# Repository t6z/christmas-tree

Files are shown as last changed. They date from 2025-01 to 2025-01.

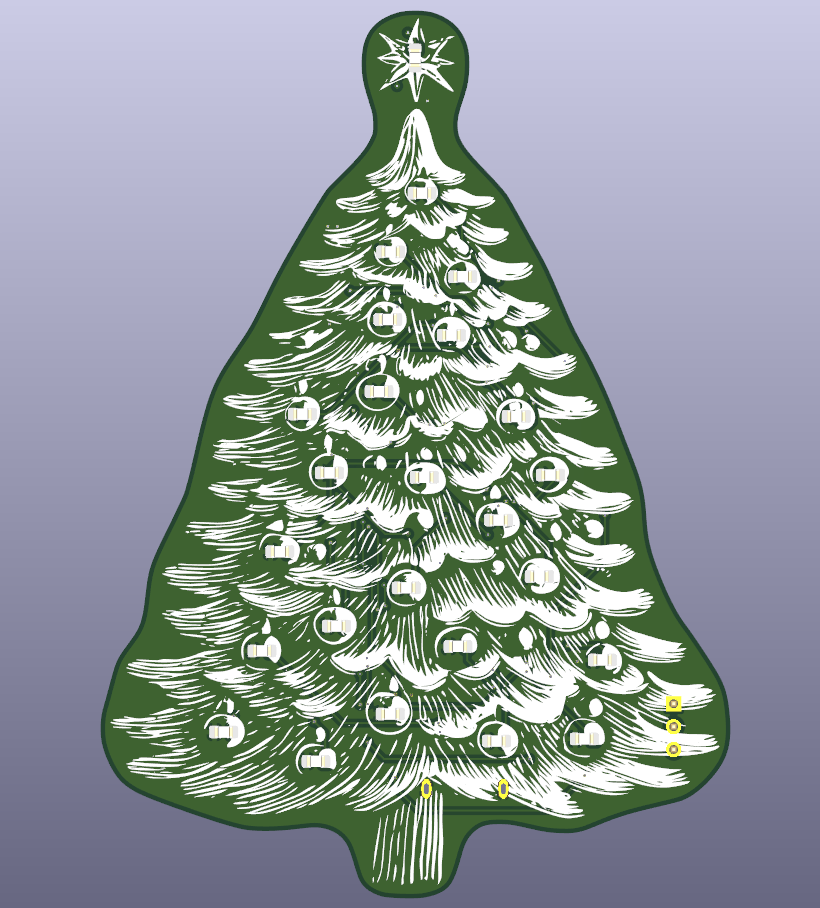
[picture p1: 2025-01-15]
images/xmas-tree-v2.png

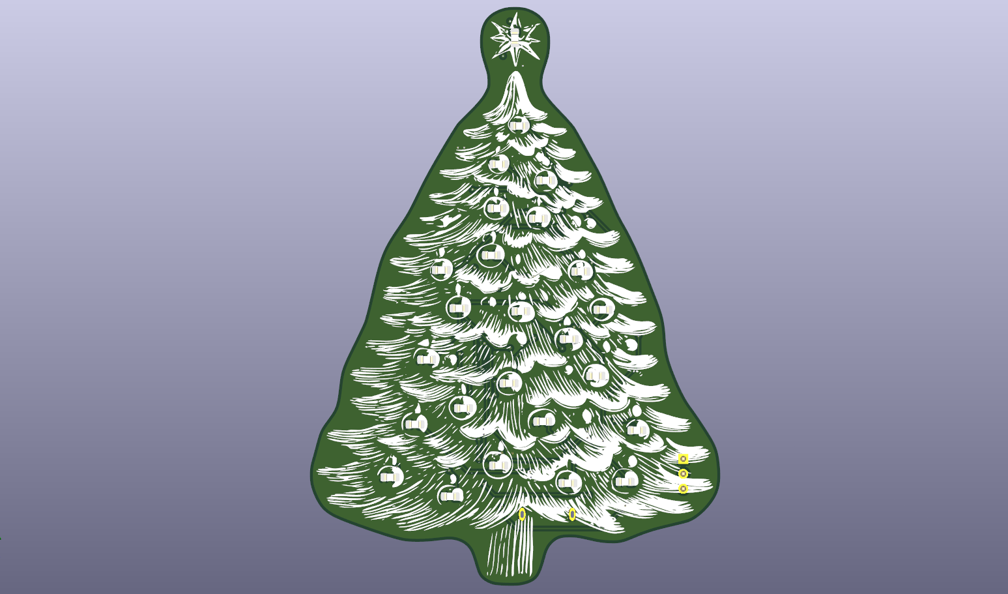
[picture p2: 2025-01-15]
images/xmas-tree.png

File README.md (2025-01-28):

# Christmas Tree

I made a little Christmas tree that lights up and plays a song through a buzzer. I wanted a simple project to expand my skills with schematic capture and PCB layout, and to see how accurate the quick turnaround prototype shops (PCBWAY) do. This project uses an ATTiny402, 3 shift registers to control the LED's, and a simple circuit to try a piezo buzzer. I used Kicad as my EDA tool. It was fun using AI + InkScape to generate different graphics for the tree and import them for the edge cut and silkscreen layers.

christmas-tree-leds

## Building Code

### Prereqs

__AVR GNU Toolchain__:

I use the AVR GNU Toolchain (GNU Binutils, GCC, AVR-LibC) to build my code. The attiny402 is supported in the AVR-LibC 2.2.0 release, but ubuntu 24.04 LTS repository only has v2.0.0 (as of December 2024). You could build GNU Binutils, GCC, and AVR-LibC from scratch, but luckily this nice guy already has: [avr-gcc-build](https://github.com/ZakKemble/avr-gcc-build)

I'm using the 14.1.0 (2024-06-14) Release. I downloaded it and extracted it into `~/avr`.

__AVR Dude__:

I downloaded the v8.0 Release of AVR Dude from the [official GitHub repository](https://github.com/avrdudes/avrdude) and extracted it into `~/avr`.

### Building

Run `make`

```bash
$ make
mkdir -p build/src
~/avr/avr-gcc-14.1.0-x64-linux/bin/avr-gcc -c -o build/src/main.o  -std=c11 -Wall -Wextra -Werror -mmcu=attiny402 -DF_CPU=3333333UL -O1 -g -gdwarf-2 -Wl,-Map,build/christmas-tree.map -DDEBUG  src/main.c
mkdir -p build/src
~/avr/avr-gcc-14.1.0-x64-linux/bin/avr-gcc -c -o build/src/notes.o  -std=c11 -Wall -Wextra -Werror -mmcu=attiny402 -DF_CPU=3333333UL -O1 -g -gdwarf-2 -Wl,-Map,build/christmas-tree.map -DDEBUG  src/notes.c
mkdir -p build/src
~/avr/avr-gcc-14.1.0-x64-linux/bin/avr-gcc -c -o build/src/rtttl.o  -std=c11 -Wall -Wextra -Werror -mmcu=attiny402 -DF_CPU=3333333UL -O1 -g -gdwarf-2 -Wl,-Map,build/christmas-tree.map -DDEBUG  src/rtttl.c
mkdir -p build/src
~/avr/avr-gcc-14.1.0-x64-linux/bin/avr-gcc -c -o build/src/tunes.o  -std=c11 -Wall -Wextra -Werror -mmcu=attiny402 -DF_CPU=3333333UL -O1 -g -gdwarf-2 -Wl,-Map,build/christmas-tree.map -DDEBUG  src/tunes.c
~/avr/avr-gcc-14.1.0-x64-linux/bin/avr-gcc -o build/christmas-tree.elf build/src/main.o build/src/notes.o build/src/rtttl.o build/src/tunes.o  -std=c11 -Wall -Wextra -Werror -mmcu=attiny402 -DF_CPU=3333333UL -O1 -g -gdwarf-2 -Wl,-Map,build/christmas-tree.map -DDEBUG 
~/avr/avr-gcc-14.1.0-x64-linux/bin/avr-objdump -h -S build/christmas-tree.elf > build/christmas-tree.lst
~/avr/avr-gcc-14.1.0-x64-linux/bin/avr-size build/christmas-tree.elf
   text	  data	   bss	   dec	   hex	filename
   3586	   156	    44	  3786	   eca	build/christmas-tree.elf
~/avr/avr-gcc-14.1.0-x64-linux/bin/avr-objcopy -j .text -j .data -O ihex build/christmas-tree.elf build/christmas-tree.hex
~/avr/avr-gcc-14.1.0-x64-linux/bin/avr-objcopy -j .text -j .data -O binary build/christmas-tree.elf build/christmas-tree.bin
```

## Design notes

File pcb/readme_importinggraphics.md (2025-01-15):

When importing the SVG's to Kicad via the File > Import > Graphics utility, I used a 0.375000 scale

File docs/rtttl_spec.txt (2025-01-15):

RTTTL Format Specifications

RTTTL (RingTone Text Transfer Language) is the primary format used to distribute 
ringtones for Nokia phones. An RTTTL file is a text file, containing the 
ringtone name, a control section and a section containing a comma separated 
sequence of ring tone commands. White space must be ignored by any reader 
application. 

Example: 
Simpsons:d=4,o=5,b=160:32p,c.6,e6,f#6,8a6,g.6,e6,c6,8a,8f#,8f#,8f#,2g

This file describes a ringtone whose name is 'Simpsons'. The control section 
sets the beats per minute at 160, the default note length as 4, and the default 
scale as Octave 5. 
<RTX file> := <name> ":" [<control section>] ":" <tone-commands>

	<name> := <char> ; maximum name length 10 characters

	<control-section> := <control-pair> ["," <control-section>]

		<control-pair> := <control-name> ["="] <control-value>

		<control-name> := "o" | "d" | "b"
		; Valid in control section: o=default scale, d=default duration, b=default beats per minute. 
		; if not specified, defaults are 4=duration, 6=scale, 63=beats-per-minute
		; any unknown control-names must be ignored

		<tone-commands> := <tone-command> ["," <tone-commands>]

		<tone-command> :=<note> | <control-pair>

		<note> := [<duration>] <note> [<scale>] [<special-duration>] <delimiter>

			<duration> := "1" | "2" | "4" | "8" | "16" | "32" 
			; duration is divider of full note duration, eg. 4 represents a quarter note

			<note> := "P" | "C" | "C#" | "D" | "D#" | "E" | "F" | "F#" | "G" | "G#" | "A" | "A#" | "B" 

			<scale> :="4" | "5" | "6" | "7"
			; Note that octave 4: A=440Hz, 5: A=880Hz, 6: A=1.76 kHz, 7: A=3.52 kHz
			; The lowest note on the Nokia 61xx is A4, the highest is B7

			<special-duration> := "." ; Dotted note

; End of specification

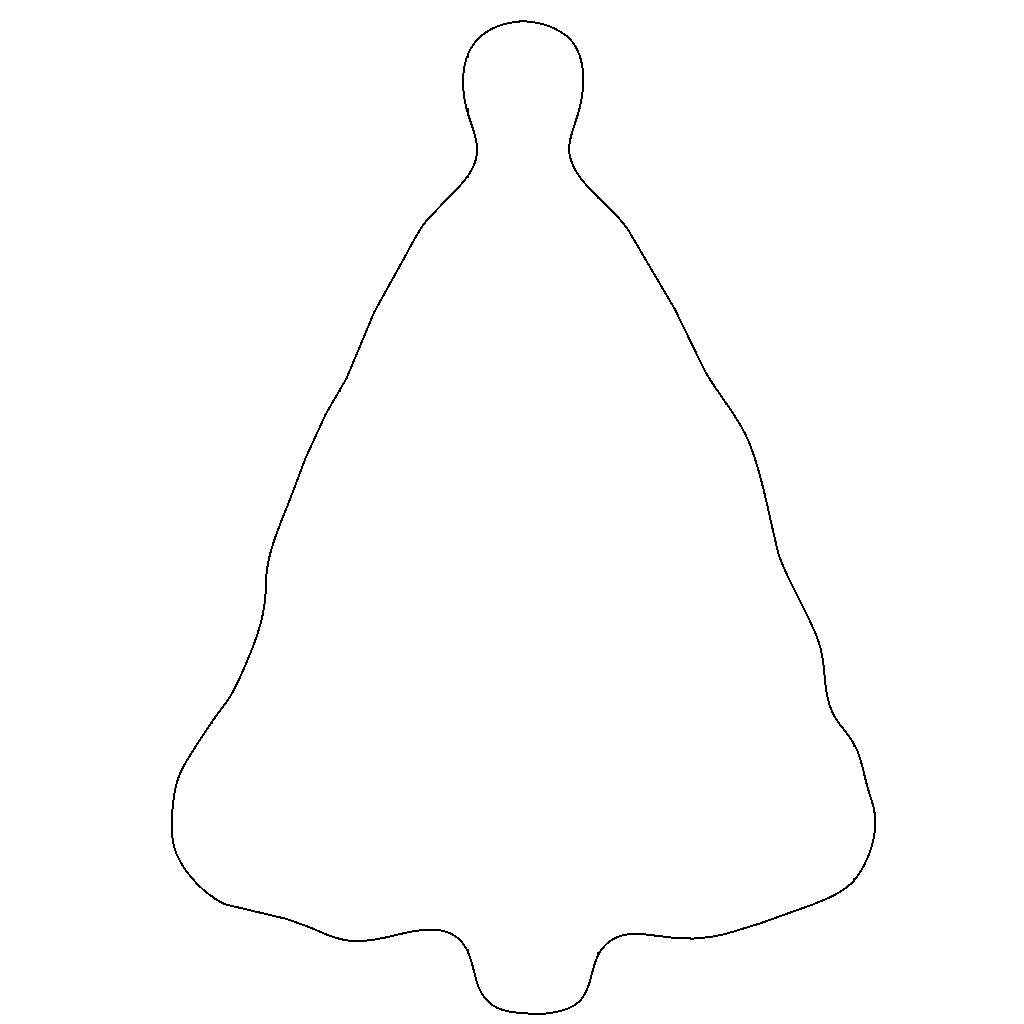
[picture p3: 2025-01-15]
images/tree-outline.png

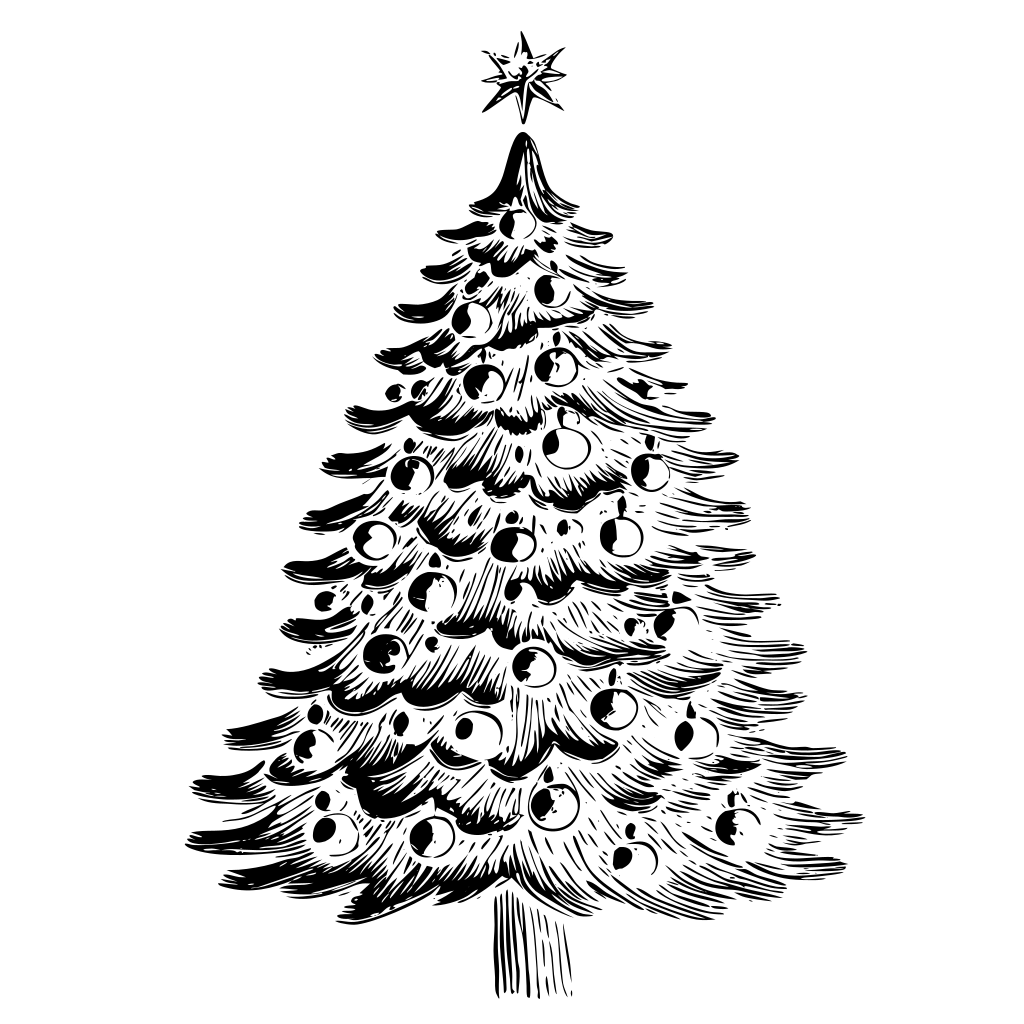
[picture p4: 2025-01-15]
images/tree.png

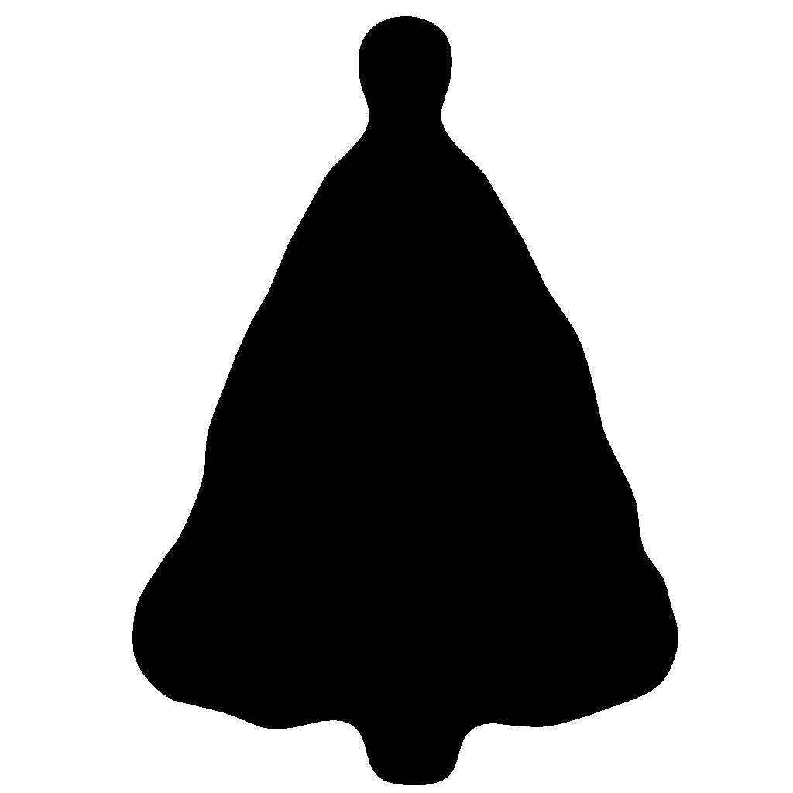
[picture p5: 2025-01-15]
images/tree-filled.png

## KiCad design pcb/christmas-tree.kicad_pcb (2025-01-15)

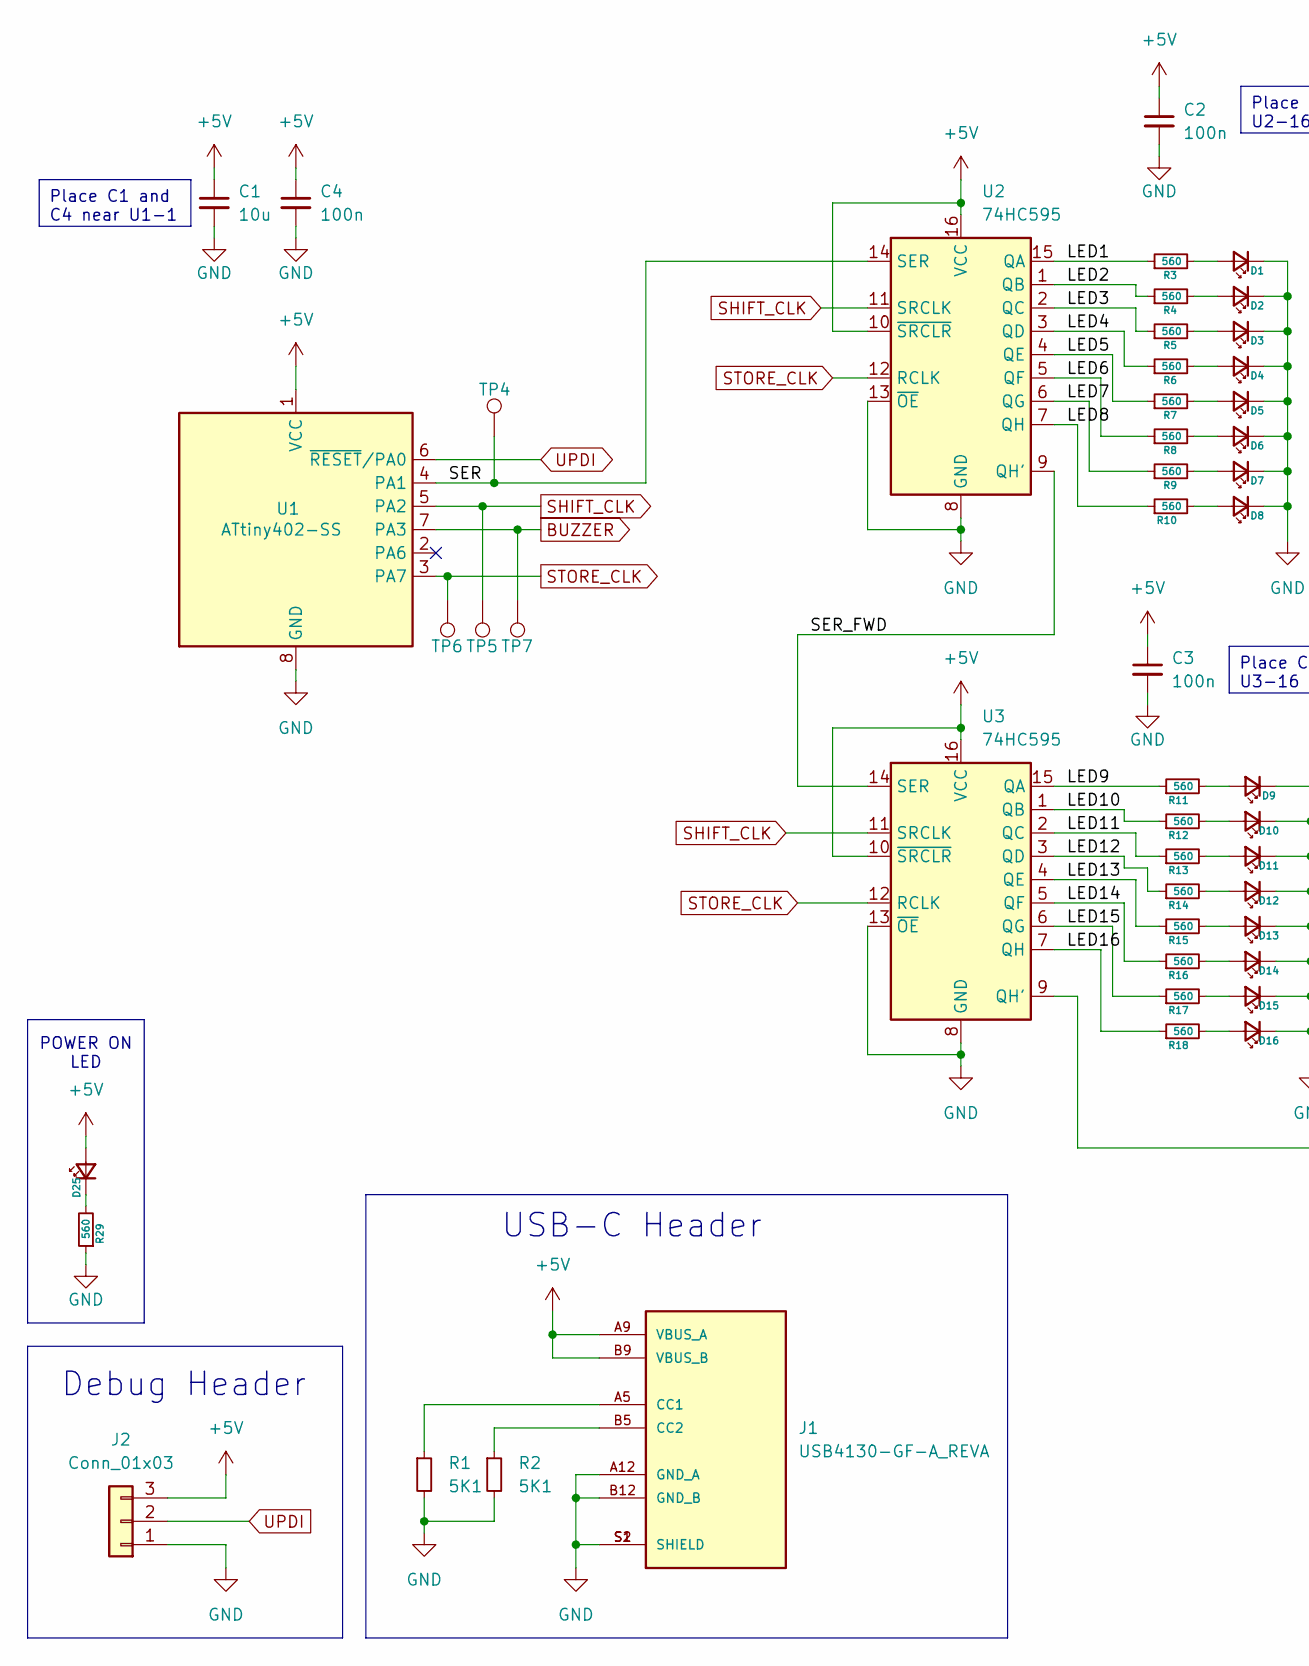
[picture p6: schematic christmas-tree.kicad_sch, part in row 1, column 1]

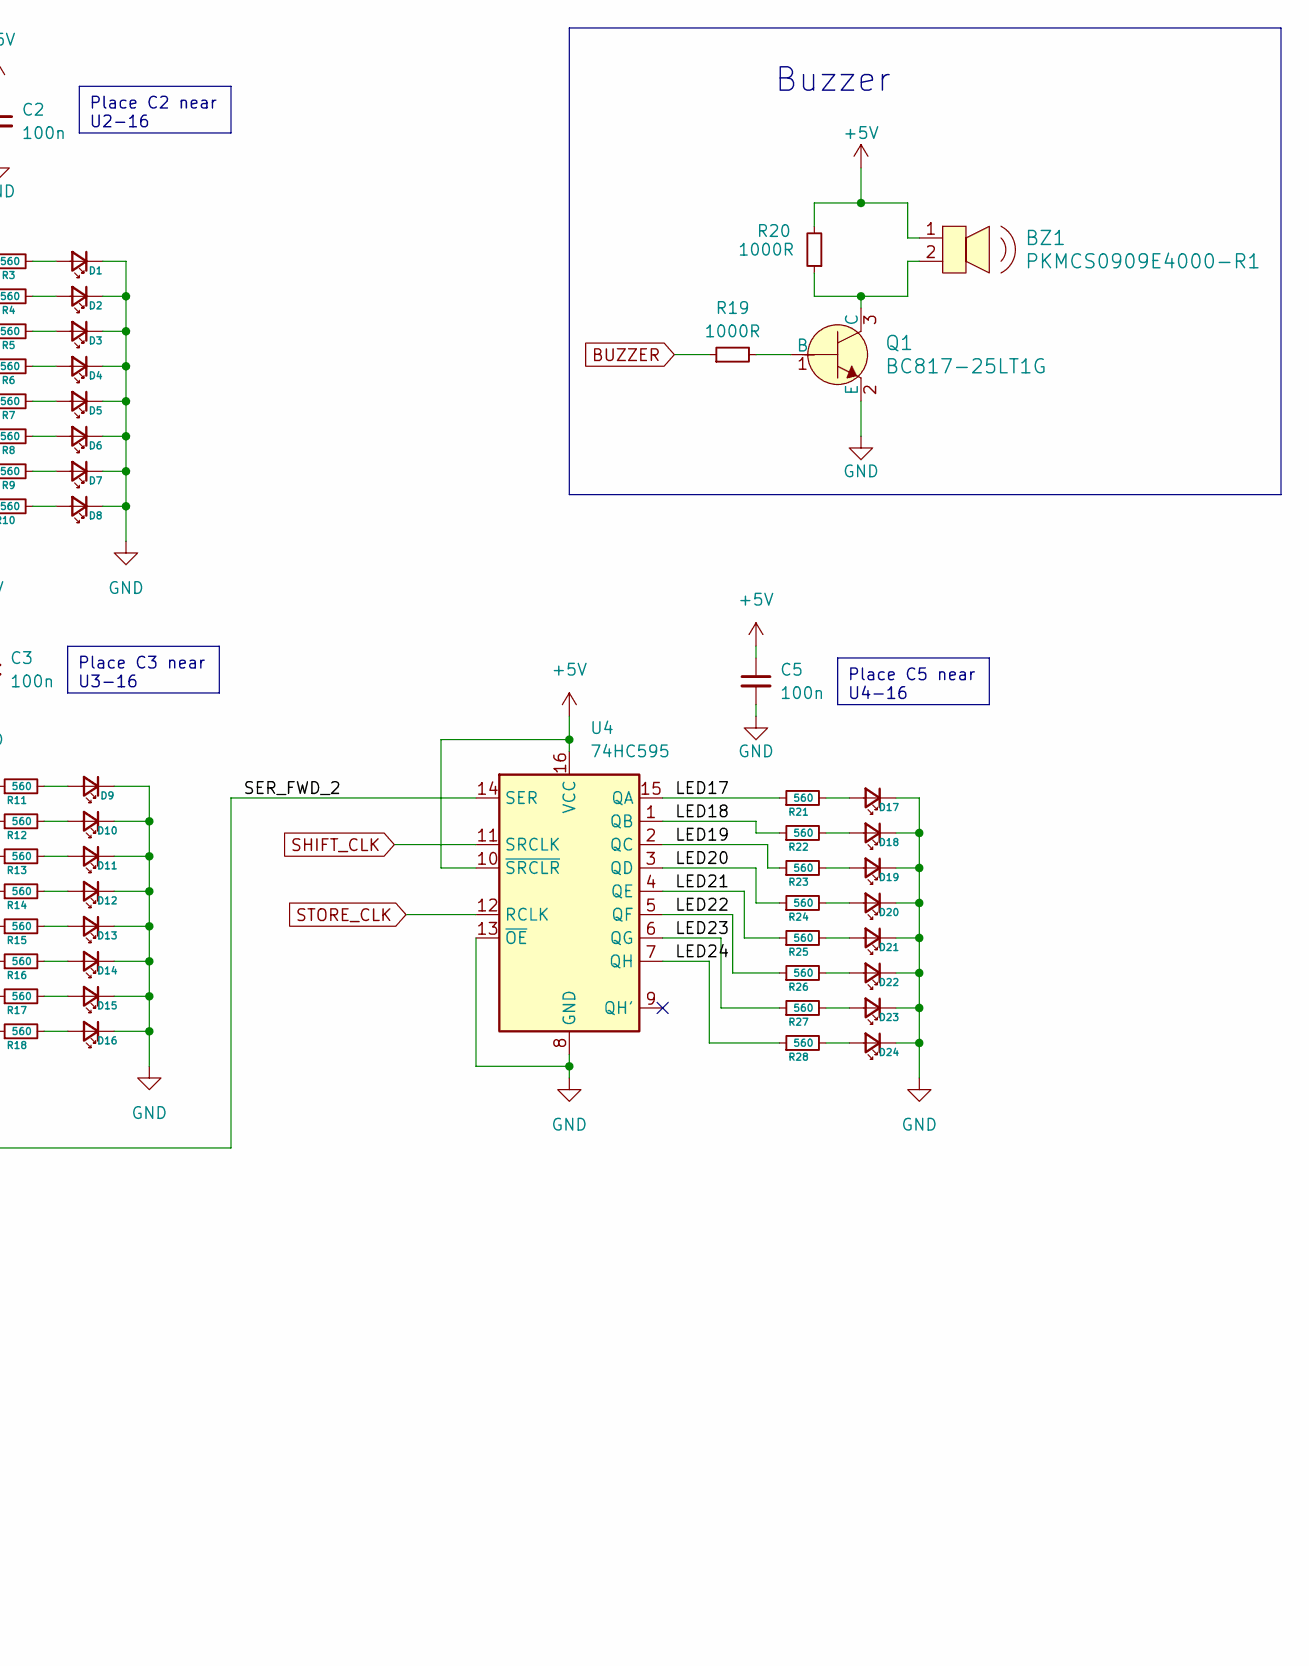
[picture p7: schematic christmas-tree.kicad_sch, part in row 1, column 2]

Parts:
BZ1: PKMCS0909E4000-R1; Piezo_9x9mm_PKMCS0909E4000-R1; MPN PKMCS0909E4000-R1; Digi-Key_PN 490-9647-1-ND
C1: 10u; C_0805_2012Metric_Pad1.18x1.45mm_HandSolder
C2, C3, C4, C5: 100n; C_0805_2012Metric_Pad1.18x1.45mm_HandSolder
D1, D2, D3, D4, D5, D6, D7, D8, D9, D10, D11, D12, D13, D14, D15, D16, D17, D18, D19, D20, D21, D22, D23, D24, D25: LED_Small; LED_0805_2012Metric_Pad1.15x1.40mm_HandSolder
J1: USB4130-GF-A_REVA; GCT_USB4130-GF-A_REVA; PARTREV A
J2: Conn_01x03; PinHeader_1x03_P2.54mm_Vertical
Q1: BC817-25LT1G; SOT-23-3; MPN BC817-25LT1G; Digi-Key_PN BC817-25LT1GOSCT-ND
R1, R2: 5K1; R_0805_2012Metric_Pad1.20x1.40mm_HandSolder
R3, R4, R5, R6, R7, R8, R9, R10, R11, R12, R13, R14, R15, R16, R17, R18, R21, R22, R23, R24, R25, R26, R27, R28, R29: 560; R_0805_2012Metric_Pad1.20x1.40mm_HandSolder
R19, R20: 1000R; R_0805_2012Metric_Pad1.20x1.40mm_HandSolder
TP4: SER; TestPoint_Pad_D1.0mm
TP5: SHIFT_CLK; TestPoint_Pad_D1.0mm
TP6: STORE_CLK; TestPoint_Pad_D1.0mm
TP7: BUZZER; TestPoint_Pad_D1.0mm
U1: ATtiny402-SS; SOIC-8_3.9x4.9mm_P1.27mm
U2, U3, U4: 74HC595; SOIC-16_3.9x9.9mm_P1.27mm

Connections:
+5V: BZ1.1, C1.1, C2.1, C3.1, C4.1, C5.1, D25.2 (A), J1.A9 (VBUS_A), J1.B9 (VBUS_B), J2.3, R20.2, U1.1 (VCC), U2.10 (~SRCLR), U2.16 (VCC), U3.10 (~SRCLR), U3.16 (VCC), U4.10 (~SRCLR), U4.16 (VCC)
/LED1: R3.1, U2.15 (QA)
/LED2: R4.1, U2.1 (QB)
/LED3: R5.1, U2.2 (QC)
/LED4: R6.1, U2.3 (QD)
/LED5: R7.1, U2.4 (QE)
/LED6: R8.1, U2.5 (QF)
/LED7: R9.1, U2.6 (QG)
/LED8: R10.1, U2.7 (QH)
/LED9: R11.1, U3.15 (QA)
/LED10: R12.1, U3.1 (QB)
/LED11: R13.1, U3.2 (QC)
/LED12: R14.1, U3.3 (QD)
/LED13: R15.1, U3.4 (QE)
/LED14: R16.1, U3.5 (QF)
/LED15: R17.1, U3.6 (QG)
/LED16: R18.1, U3.7 (QH)
/LED17: R21.1, U4.15 (QA)
/LED18: R22.1, U4.1 (QB)
/LED19: R23.1, U4.2 (QC)
/LED20: R24.1, U4.3 (QD)
/LED21: R25.1, U4.4 (QE)
/LED22: R26.1, U4.5 (QF)
/LED23: R27.1, U4.6 (QG)
/LED24: R28.1, U4.7 (QH)
/SER: TP4.1, U1.4 (PA1), U2.14 (SER)
/SER_FWD: U2.9 (QH'), U3.14 (SER)
/SER_FWD_2: U3.9 (QH'), U4.14 (SER)
BUZZER: R19.1, TP7.1, U1.7 (PA3)
GND: C1.2, C2.2, C3.2, C4.2, C5.2, D1.1 (K), D2.1 (K), D3.1 (K), D4.1 (K), D5.1 (K), D6.1 (K), D7.1 (K), D8.1 (K), D9.1 (K), D10.1 (K), D11.1 (K), D12.1 (K), D13.1 (K), D14.1 (K), D15.1 (K), D16.1 (K), D17.1 (K), D18.1 (K), D19.1 (K), D20.1 (K), D21.1 (K), D22.1 (K), D23.1 (K), D24.1 (K), J1.A12 (GND_A), J1.B12 (GND_B), J1.S1 (SHIELD), J1.S2 (SHIELD), J2.1, Q1.2 (E), R1.2, R2.2, R29.1, U1.8 (GND), U2.8 (GND), U2.13 (~OE), U3.8 (GND), U3.13 (~OE), U4.8 (GND), U4.13 (~OE)
unnamed: D1.2 (A), R3.2
unnamed: D2.2 (A), R4.2
unnamed: D3.2 (A), R5.2
unnamed: D4.2 (A), R6.2
unnamed: D5.2 (A), R7.2
unnamed: D6.2 (A), R8.2
unnamed: D7.2 (A), R9.2
unnamed: D8.2 (A), R10.2
unnamed: D9.2 (A), R11.2
unnamed: D10.2 (A), R12.2
unnamed: D11.2 (A), R13.2
unnamed: D12.2 (A), R14.2
unnamed: D13.2 (A), R15.2
unnamed: D14.2 (A), R16.2
unnamed: D15.2 (A), R17.2
unnamed: D16.2 (A), R18.2
unnamed: D17.2 (A), R21.2
unnamed: D18.2 (A), R22.2
unnamed: D19.2 (A), R23.2
unnamed: D20.2 (A), R24.2
unnamed: D21.2 (A), R25.2
unnamed: D22.2 (A), R26.2
unnamed: D23.2 (A), R27.2
unnamed: D24.2 (A), R28.2
unnamed: D25.1 (K), R29.2
unnamed: J1.A5 (CC1), R1.1
unnamed: J1.B5 (CC2), R2.1
unnamed: Q1.1 (B), R19.2
unnamed: BZ1.2, Q1.3 (C), R20.1
SHIFT_CLK: TP5.1, U1.5 (PA2), U2.11 (SRCLK), U3.11 (SRCLK), U4.11 (SRCLK)
STORE_CLK: TP6.1, U1.3 (PA7), U2.12 (RCLK), U3.12 (RCLK), U4.12 (RCLK)
UPDI: J2.2, U1.6 (~RESET/PA0)

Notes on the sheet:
Place C1 and C4 near U1-1
Place C3 near U3-16
Place C5 near U4-16
Place C2 near U2-16
POWER ON LED
Debug Header
USB-C Header
Buzzer

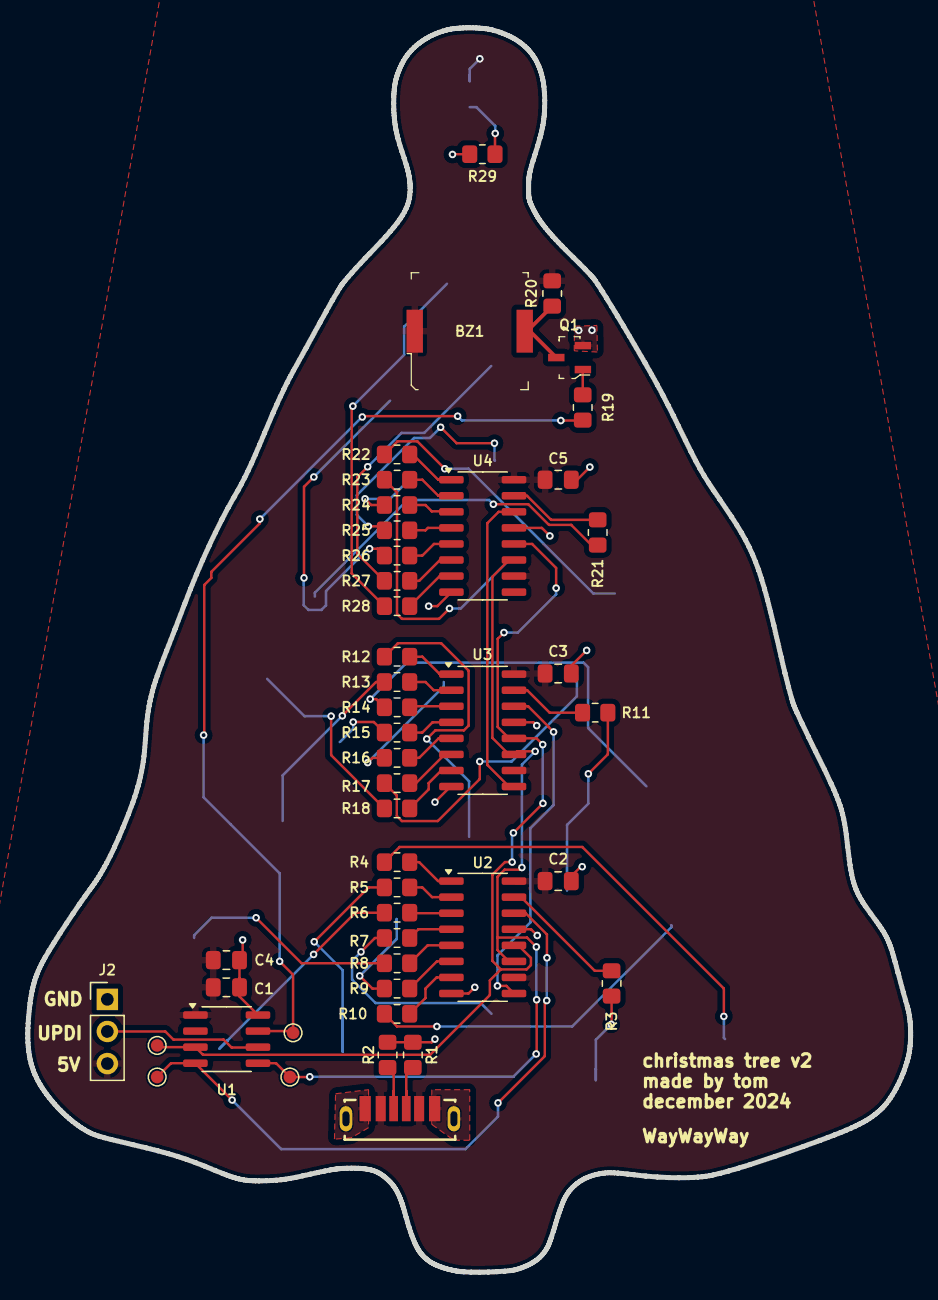
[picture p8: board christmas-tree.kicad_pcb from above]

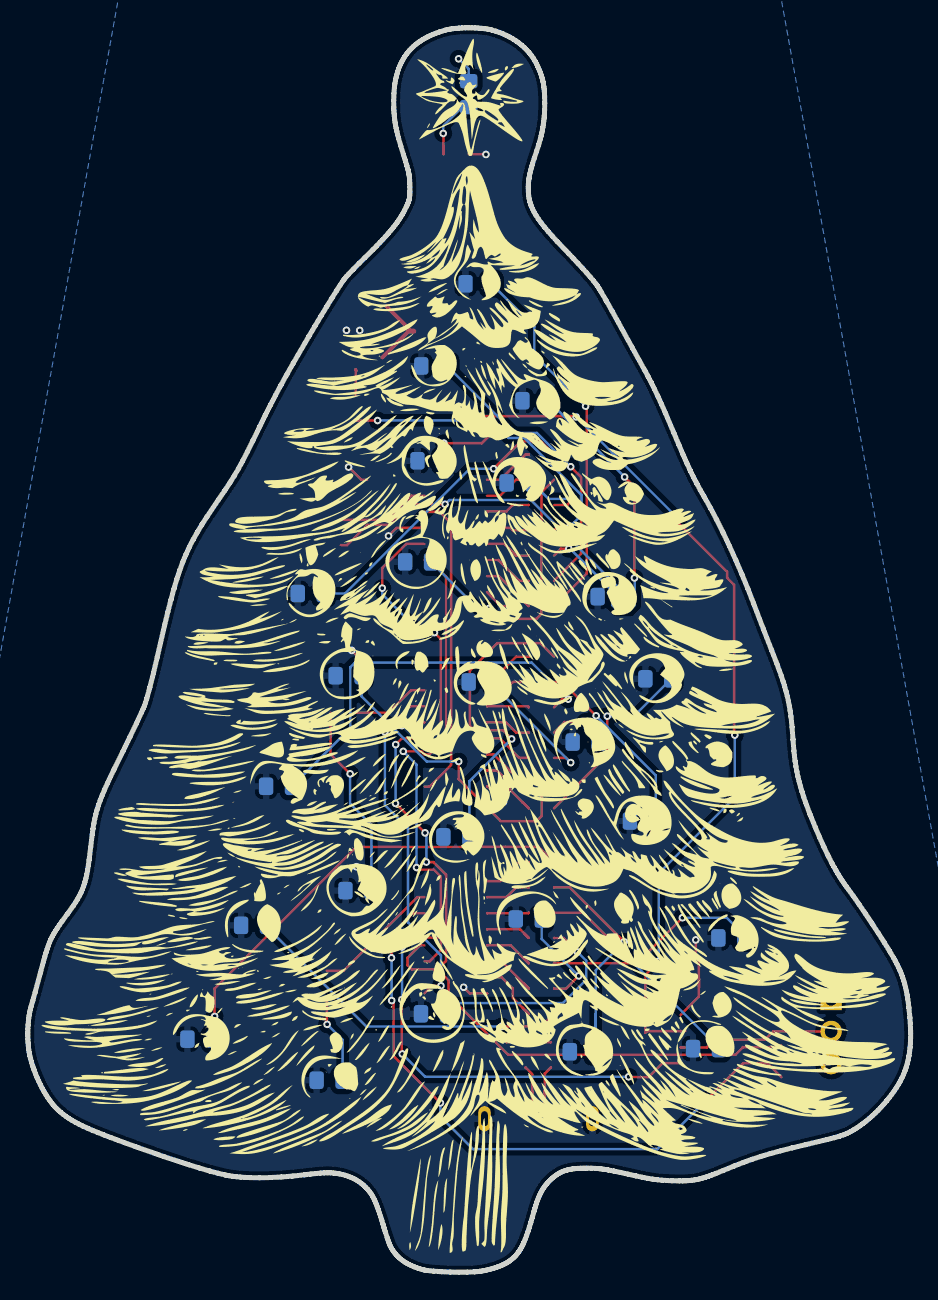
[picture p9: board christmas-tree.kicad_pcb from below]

Board: 2 copper layers, 69.8 x 98.4 mm, 71 parts (25 on the bottom side), 62 nets.

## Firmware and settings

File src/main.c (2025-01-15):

#include <avr/io.h>
#include <avr/interrupt.h>
#include <util/delay.h>

#include "notes.h"
#include "rtttl.h"
#include "tunes.h"

#define HIGH (1U)
#define LOW  (0U)

#define PIN_SER (1U) /* PA1 */
#define PIN_SHIFT_CLK (2U) /* PA2 */
#define PIN_STORE_CLK (7U) /* PA7 */

#define NUM_LEDS (24U)

Rtttl_Tune_s tune;
volatile Rtttl_Note_s next_note = {
   .d = RTTTL_D1,
   .o = RTTTL_O4,
   .p = RTTTL_PC,
   .s = 0
};
uint16_t cnts_default_note = 0;

uint8_t led_duration[3] = {9,11,13};
uint8_t led_duration_cnt = 0;
uint16_t led_counter = 0;
uint8_t led_turnon[NUM_LEDS] = {0};
uint8_t led_order[NUM_LEDS] = {12, 7, 15, 13, 19, 23, 18, 6, 16, 20, 3, 9, 21, 14, 1, 17, 0, 10, 8, 4, 5, 11, 2, 22};
uint32_t output = 0;
uint8_t counter = 0;

void digitalWrite(uint8_t pin, uint8_t level) {
   if (level) {
      VPORTA_OUT |= (uint8_t)(1U<<pin);
   } else {
      VPORTA_OUT &= (uint8_t)(~(1U<<pin));
   }
}

void shiftOut(uint8_t data)
{
   for (uint8_t i = 0; i < 8; i++)  {
      /* Update serial data pin */
      digitalWrite(PIN_SER, (data & (1 << i)));
      /* Cycle shift clock */
      digitalWrite(PIN_SHIFT_CLK, HIGH);
      digitalWrite(PIN_SHIFT_CLK, LOW);
   }
}

void updateShiftRegister(uint32_t data) {
   /* Set store clock pin low */
   digitalWrite(PIN_STORE_CLK,LOW);

   /* shift upper 8 bits out */
   shiftOut((uint8_t)(data&0xFF));
   shiftOut((uint8_t)((data>>8)&0xFF));
   shiftOut((uint8_t)((data>>16)&0xFF));

   /* Setting store clock pin high again updates shift register's output */
   digitalWrite(PIN_STORE_CLK,HIGH);
}

void update_note (Rtttl_Pitch_e pitch, Rtttl_Octave_e octave) {
   uint16_t period, compare;

   if (pitch == RTTTL_PP) {
      TCA0.SINGLE.CMP0BUF = 0;
   } else {
      if (octave == RTTTL_O4) {
         period = tca0_per[pitch-1];
         compare = tca0_cmp0[pitch-1];
      } else {
         period = tca0_per[pitch-1] >> (octave-4);
         compare = tca0_cmp0[pitch-1] >> (octave-4);
      }
      TCA0.SINGLE.PERBUF = period;
      TCA0.SINGLE.CMP0BUF = compare;
   }
}

void init_clock (void) {
   /* set the 32KHz Oscillator in Run Standby mode so it is on for the RTC */
   CLKCTRL.OSC32KCTRLA = CLKCTRL_RUNSTDBY_bm;
   /* wait for 32KHz Oscillator to be stable */
   while (!((CLKCTRL.MCLKSTATUS&0x10)==0x10));
}

/* Initialize Port */
void init_pins (void) {
   /* GPIO pins are cleared upon RESET */
   /* set PA1,2,3,7 as output pins */
   PORTA.DIR = PIN1_bm | PIN2_bm | PIN3_bm | PIN7_bm;
}

/* Initialize Real Time Clock */
void init_rtc (void) {
   /* select 32KHz clock */
   RTC.CLKSEL = 0;
   /* Set CMP value */
   RTC.CMP = 0xFFFF;
   /* Enable CMP interrupt */
   RTC.INTCTRL = RTC_CMP_bm;
   /* Enable RTC */
   RTC.CTRLA = RTC_RTCEN_bm;
}

/* Initialize Timer A */
void init_tca0 (void) {
   /* Enable CMP0 and set Waveform Generation Mode to Dual-Slope PWM */
   TCA0.SINGLE.CTRLB = TCA_SINGLE_CMP0EN_bm | TCA_SINGLE_WGMODE_DSBOTTOM_gc;

   /* Set Period */
   TCA0.SINGLE.PERBUF = 0x3FFU;
   /* Set CMP0 */
   TCA0.SINGLE.CMP0BUF = 0x1FFU;

   /* Select Clock Divider and Enable Timer */
   TCA0.SINGLE.CTRLA = TCA_SINGLE_CLKSEL_DIV4_gc | TCA_SINGLE_ENABLE_bm;
}

/* Initialize Timer B */
void init_tcb0 (void) {
   TCB0.CCMP = 0xFFF;
   TCB0.INTCTRL = TCB_CAPT_bm;
   TCB0.CTRLA = TCB_CLKSEL_CLKTCA_gc | TCB_ENABLE_bm;
}

void init (void) {
   init_clock();
   init_pins();
   init_rtc();
   init_tca0();
   init_tcb0();
}

void init_tune (char* tune_p) {
   tune.c = 0;
   tune.st = RTTTL_NOERR;
   tune.t = &tune_p[0];
   rtttl_init(&tune);

   cnts_default_note = (uint16_t)((60.0/tune.b)*32768);

   /* if the default length is not a quarter note */
   if (tune.d > RTTTL_D4) {
      cnts_default_note = cnts_default_note * (tune.d/RTTTL_D4);
   } else if (tune.d < RTTTL_D4) {
      cnts_default_note = cnts_default_note * (RTTTL_D4/tune.d);
   }
}

int main (void) {
   uint8_t playing_tune = 0;

   init();
   sei(); /* enable interrupts */

   TCA0.SINGLE.CMP0BUF = 0;

   init_tune((char*)&tune_green[0]);
   next_note = rtttl_next_note(&tune);
   playing_tune = 1;
   /* everything is handled in interrupts */
   /* loop forever */
   for(;;) {
      if (!playing_tune) {
         _delay_ms(5000);
         init_tune((char*)&tune_green[0]);
         next_note = rtttl_next_note(&tune);

         playing_tune = 1;
      } else if (tune.st == RTTTL_DONE){
         playing_tune = 0;
      }
   }

   return 0;
}

ISR(TCB0_INT_vect) {
   if (counter%13==0) {
      led_turnon[led_order[led_counter]] = led_duration[led_duration_cnt];
      led_duration_cnt++;
      if (led_duration_cnt%3==0) led_duration_cnt=0;
      led_counter++;
      if (led_counter%NUM_LEDS==0) led_counter=0;
      output = 0;
      for (uint8_t i = 0; i < NUM_LEDS; i++) {
         if (led_turnon[i]) {
            led_turnon[i]--;
            output |= ((uint32_t)1)<<i;
         }
      }
      updateShiftRegister(output);
   }

   /* update counter */
   counter++;
   if (counter%50==0) counter = 0;
   /* Clear the interrupt flag */
   TCB0.INTFLAGS = TCB_CAPT_bm;
}

ISR(RTC_CNT_vect) {
   uint16_t cnt = RTC.CNT;
   uint16_t cnt_add;

   update_note(next_note.p,next_note.o);

   /* if its the default length */
   if (tune.d == next_note.d) {
      cnt_add = cnts_default_note;
   } else if (((uint8_t)(tune.d/next_note.d)) > 0) {
      cnt_add = (uint16_t)(cnts_default_note * (tune.d/next_note.d));
   } else {cnt_add = (uint16_t)(cnts_default_note / (next_note.d/tune.d));}

   if (next_note.s) {cnt_add += (cnt_add>>1);}

   next_note = rtttl_next_note(&tune);

   RTC.CMP = cnt+cnt_add;
   /* Clear the Compare Match Interrupt Flag */
   RTC.INTFLAGS = RTC_CMP_bm;
}
